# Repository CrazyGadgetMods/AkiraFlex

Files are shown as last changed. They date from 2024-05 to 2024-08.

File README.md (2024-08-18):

# AkiraFlex
AkiraFlex is an N64 RDRAM termination flex PCB, designed to be a low-profile replacement for the stock expansion port + trimmed jumper pak combo commonly used in existing N64 portables. It was inspired by the ["Akira Method"](https://bitbuilt.net/forums/index.php?threads/lockdown-64.4175/post-46301) of digging up the expansion port pads and deadbugging the RDRAM termination circuit.

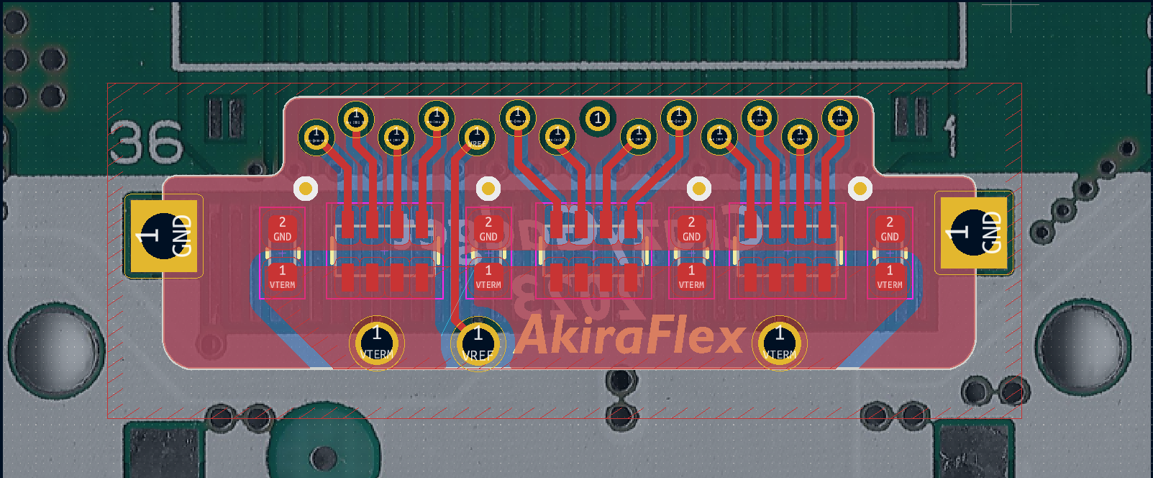
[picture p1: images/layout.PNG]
\
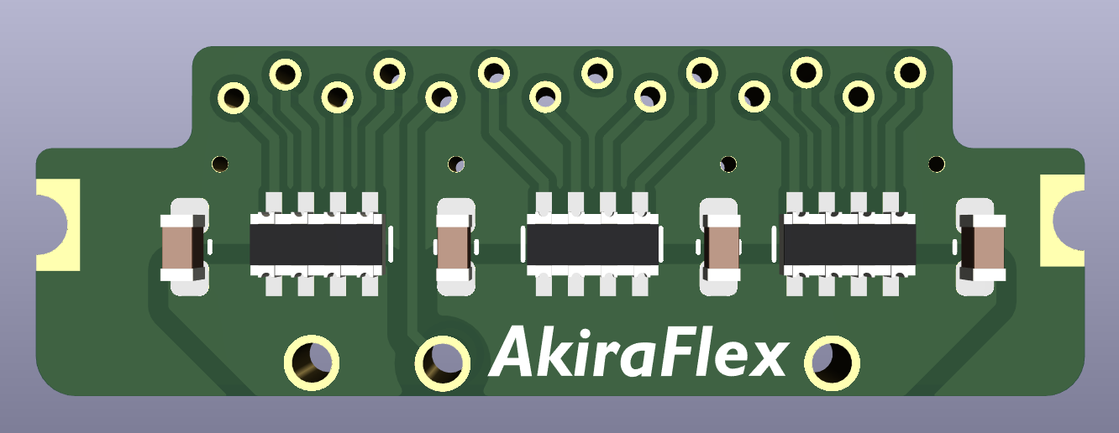
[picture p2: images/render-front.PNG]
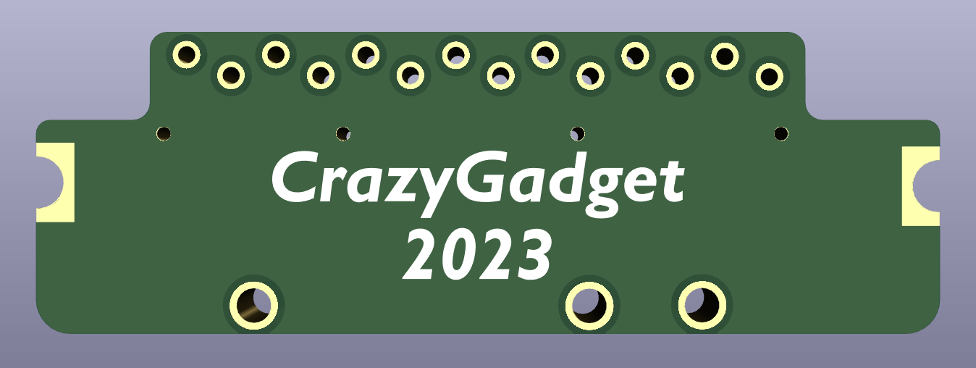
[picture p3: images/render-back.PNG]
 

## Installation
Components for the flex can either be pulled from an original N64 jumper / expansion pak, or can be bought brand new. All RAs are 1206-sized 51 Ohm, all caps are 0603-sized 1uF.

This flex was originally designed around a NUS-CPU-03 board, which has test points on the RDRAM traces between the RAM and the expansion port. If you are using this on a non-Rev 3 board (such as the Rev 4 board I installed in on here), you will need to scratch the traces as shown. Additionally, the VREF and VTERM vias must be scratched / tinned. Though apparently not necessary according to some testing Cy (of the BitBuilt Forums) has done, it is best practice to dig up the existing expansion port pads, as they will act as stubs for the RDRAM; not digging them up may lead to the board not booting / possible instabilities in-game. Once all the necessary vias / traces have been scratched / tinned / dug up, the flex can be installed on the board. Once installed, run a magnet wire from the pad shown below and the bottom of R33 on the N64 (rambus clock output from the mx8330).

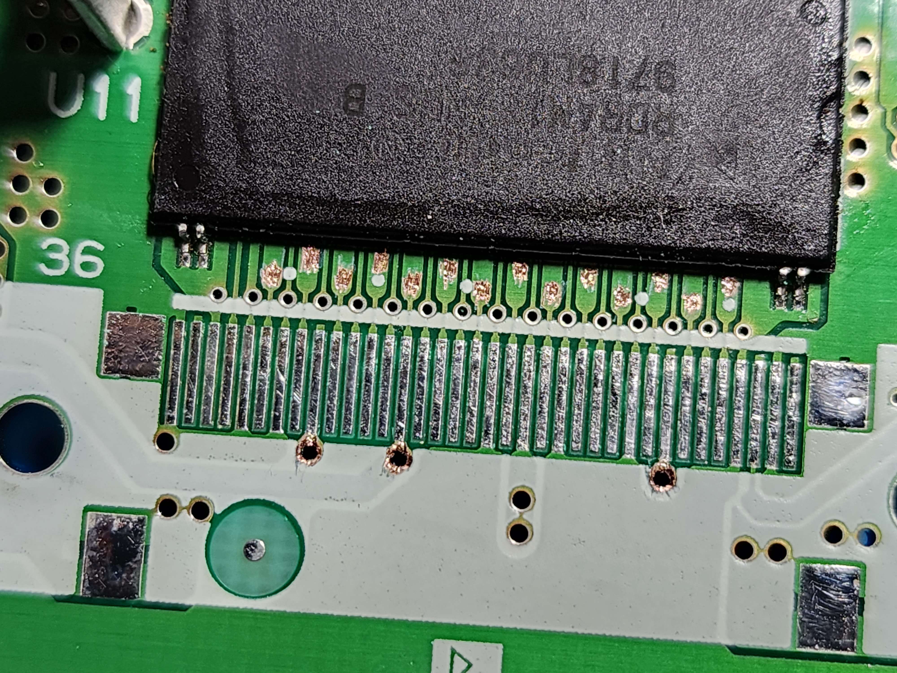
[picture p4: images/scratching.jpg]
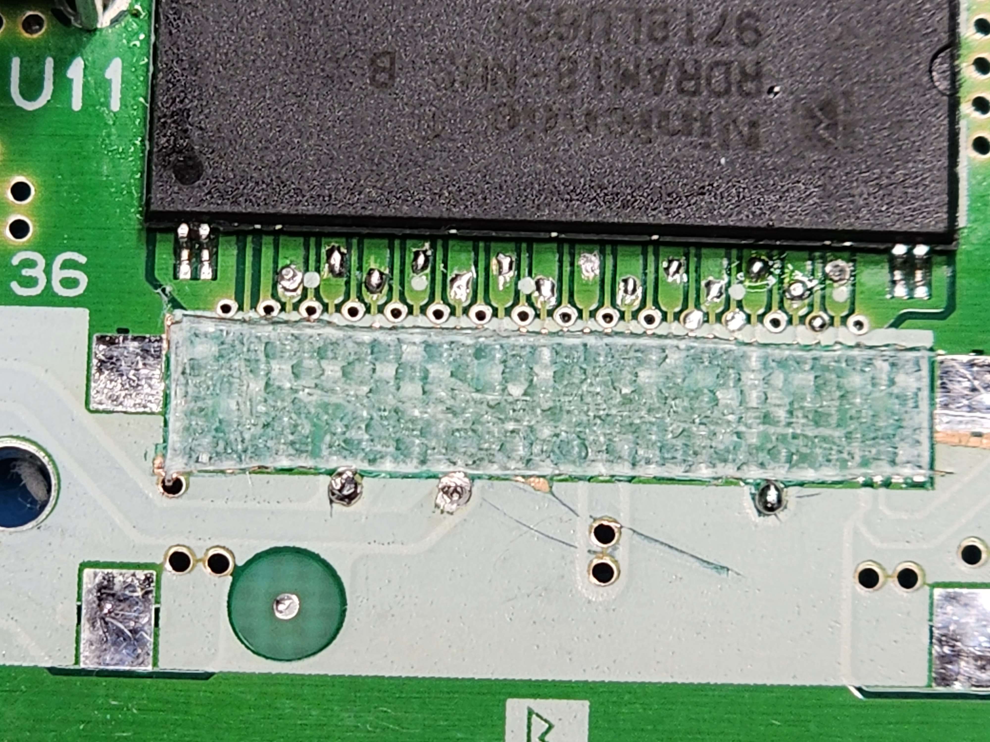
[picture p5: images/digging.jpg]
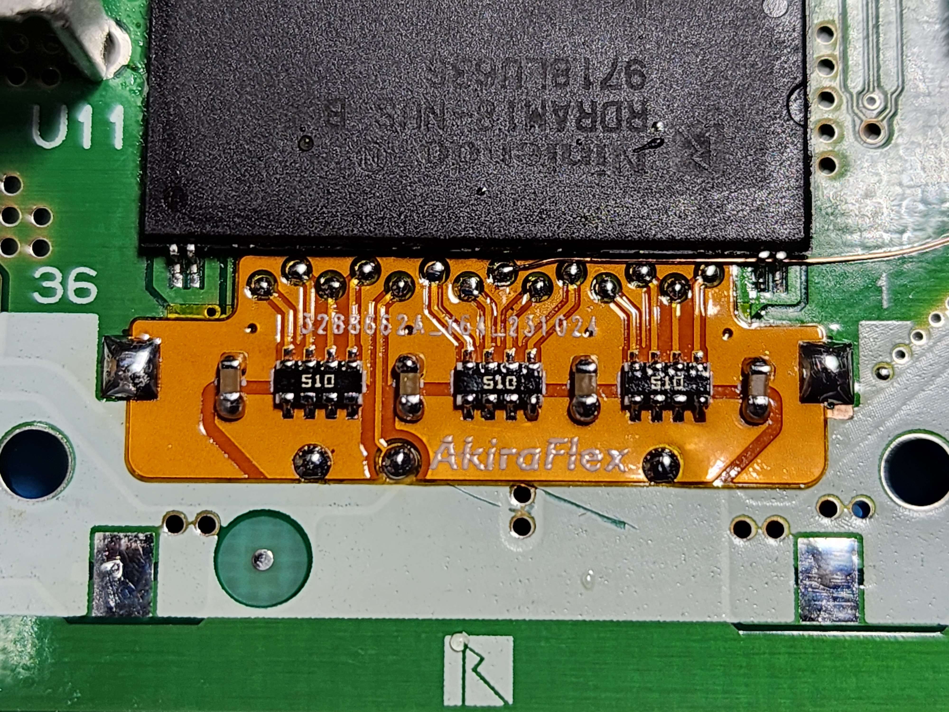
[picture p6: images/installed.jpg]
  

## Testing
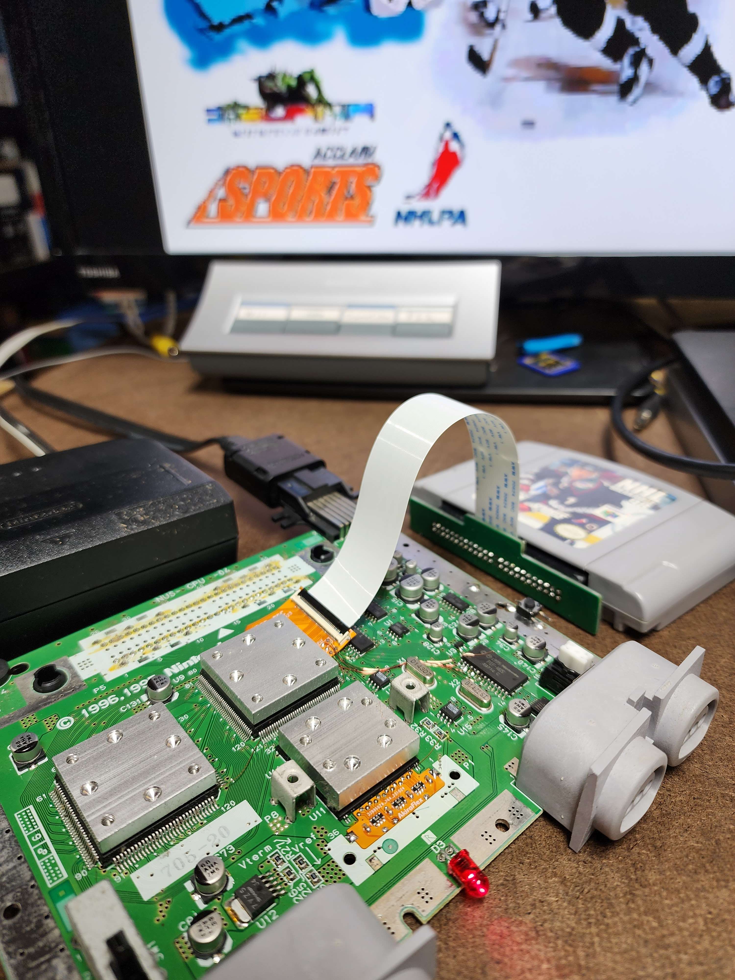
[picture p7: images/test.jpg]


## Purchasing
If interested in purchasing an AkiraFlex kit (blank flex + RAs and capacitors), [I am selling them on my Etsy store!](https://www.etsy.com/listing/1780345019)

## Credits
- [Akira](https://bitbuilt.net/forums/index.php?members/akira.1105/): [creating the original method for deadbugging the RDRAM termination circuit](https://bitbuilt.net/forums/index.php?threads/lockdown-64.4175/post-46301)
- [Noah](https://bitbuilt.net/forums/index.php?members/noah.1/): [inspiration from his unfinished Terminator 64 flex](https://bitbuilt.net/forums/index.php?threads/fusion64.3139/post-37558)
- [Cy](https://bitbuilt.net/forums/index.php?members/cy.7203/): [inspiration from his Terminator 64 flex](https://bitbuilt.net/forums/index.php?threads/ashida-64-working-title-n64-portable.5529/post-64147)
- [YveltalGriffin](https://github.com/mackieks): answering my many, many, *many* questions during my N64 anatomy deep-dive and helping me understand RDRAM / the Akira Method
- [BitBuilt](https://bitbuilt.net/): Being the best modding community out there!

## License
Solderpad Hardware License v2.1

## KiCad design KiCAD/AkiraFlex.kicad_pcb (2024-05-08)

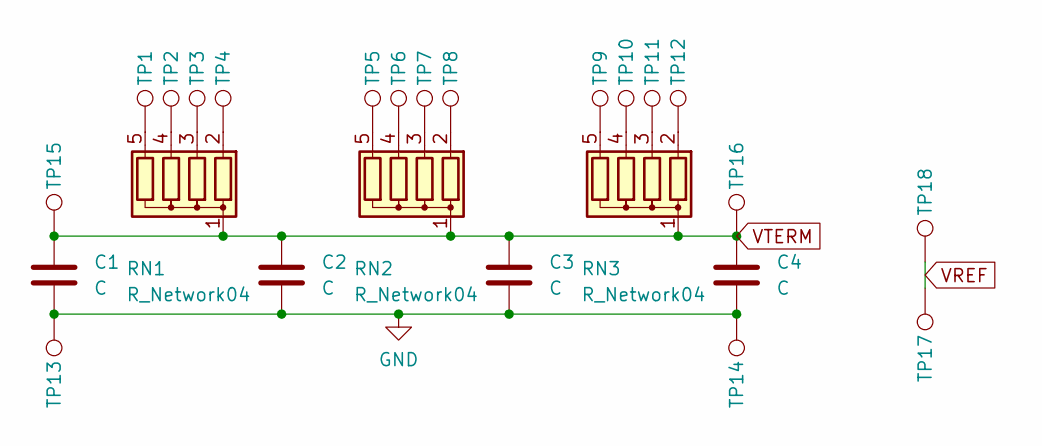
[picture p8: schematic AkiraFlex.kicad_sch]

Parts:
C1, C2, C3, C4: C; C_0603_1608Metric
RN1, RN2, RN3: R_Network04; R_Array_Concave_4x0603
TP1, TP2, TP3, TP4, TP5, TP6, TP7, TP8, TP9, TP10, TP11, TP12, TP18: TestPoint; RAM Via
TP13, TP14: TestPoint; RAM GND
TP15, TP16, TP17: TestPoint; RAM Via 2

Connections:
GND: C1.2, C2.2, C3.2, C4.2, TP13.1, TP14.1
unnamed: RN1.2 (R1), TP4.1
unnamed: RN1.3 (R2), TP3.1
unnamed: RN1.4 (R3), TP2.1
unnamed: RN1.5 (R4), TP1.1
unnamed: RN2.2 (R1), TP8.1
unnamed: RN2.3 (R2), TP7.1
unnamed: RN2.4 (R3), TP6.1
unnamed: RN2.5 (R4), TP5.1
unnamed: RN3.2 (R1), TP12.1
unnamed: RN3.3 (R2), TP11.1
unnamed: RN3.4 (R3), TP10.1
unnamed: RN3.5 (R4), TP9.1
VREF: TP17.1, TP18.1
VTERM: C1.1, C2.1, C3.1, C4.1, RN1.1 (common), RN2.1 (common), RN3.1 (common), TP15.1, TP16.1

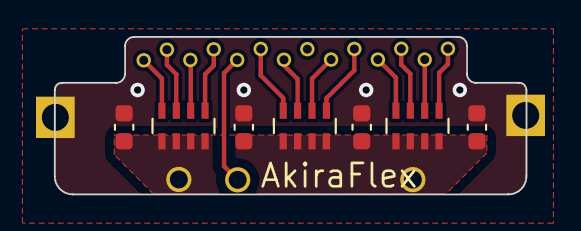
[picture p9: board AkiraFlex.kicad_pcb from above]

Board: 2 copper layers, 26.2 x 8.8 mm, 25 parts (0 on the bottom side), 15 nets.
